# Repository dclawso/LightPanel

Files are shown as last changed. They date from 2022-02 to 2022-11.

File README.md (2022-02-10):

# LED light panel
So, I put my new Creality Ender 3 v2 in an enclosure. Now my PiCam can't see anything, so I needed some light. Since I love to tinker, I decided to build a LED light source for inside the enclosure.

I found a 8x32 LED panel [ACEIRMC 2pcs WS2812 5050SMD Individual Addressable 8X32 256 Pixels LED Matrix](https://www.amazon.com/dp/B08XZHRV3S?th=1), under $20 each. 

## The 3d printed stuff

Since the panel was flexible, I needed a frame to hold it. This led to the beginning of a 3d print project. The SCAD files are in the models folder.
The parts consit of two halves for the light panel and a control box for the power supply and the microcontroller.

NOTE: There currently is no cover for the control box.

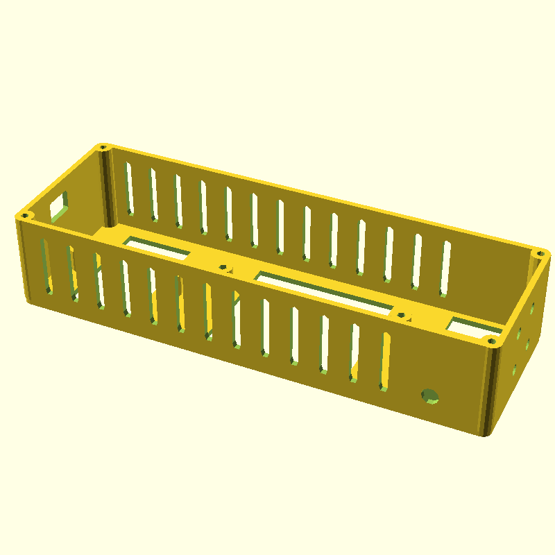
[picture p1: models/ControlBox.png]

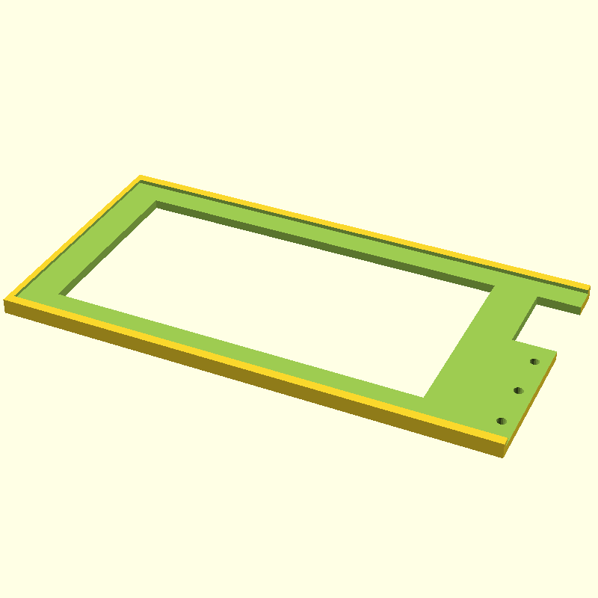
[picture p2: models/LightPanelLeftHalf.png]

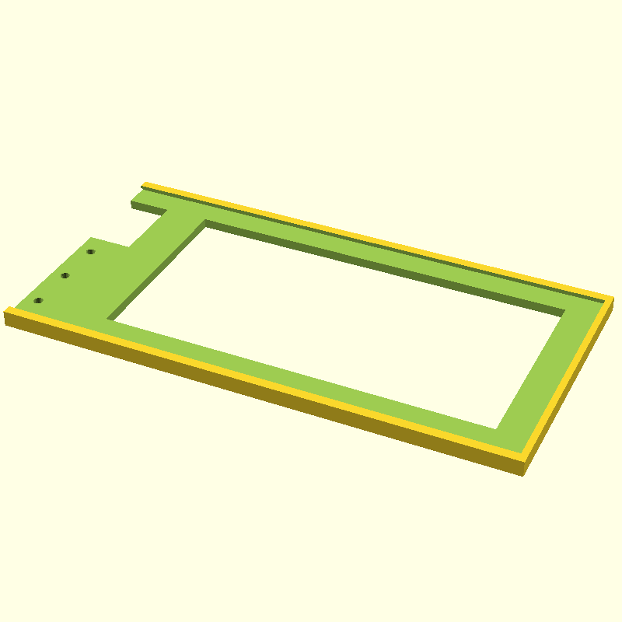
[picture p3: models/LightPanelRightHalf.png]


## The electronics

The brains of the light panel is an Arduino Nano v3. The power supply is a [Teyleten Robot 100W 6A DC-DC Buck Converter 10-90V](https://www.amazon.com/dp/B09FNBSZTR) which is way more power than required, but it has the capability to handle the 48V output available from the Ender 3's power supply and can handle enough current for the LED panel.

Connnection to the Raspberry Pi running [Octoprint](https://octoprint.org/) was originally going to be serial over USB, but there were two problems, another cable, and 5v from the Pi colliding with 5v from the high power powersupply. To solve this issue, add an HC06 bluetooth dongle.

## The software

The original idea was just to have th Arduino set all of the LEDs to max white and let it go. Where is the fun in that? After playing with several of the [FastLED](https://fastled.io/) examples, more colors and different settings were needed.

A simple command set was needed to allow for changing the color and intensity of the LEDs. This simple command set only supports setting the entire panel to one color, although it is possible for the Nano to set color for each LED individually.

The communication with the bluetooth dongle is via [AltSoftSerial](https://www.arduino.cc/reference/en/libraries/altsoftserial/). Since FastLED can hold the atmel processor for about 1.6ms to update the panel and AltSoftSerial is only able to delay an interrupt by about 1 bit time, the command set would have to be very simple.

There are currently two commands:

| Command|Usage | Description |
| -- | -- | -- |
| i | iddd | Set the intensity, replace ddd with a value between 0-100 to set intensity percentage. |
| c | cRRGGBB | Set the color of the panel, RRGGBB is the hex value for the RGB color. |
| p | pdddRRGGBBrrggbb | Set the LED panel as an progress meter. ddd is the percentage complete. RRGGBB is the hex value for the foreground color, rrggbb is the hex value for the background color. The percentage of the panel closest to the the provided progress percentage will consist of the foreground color.

The commands are received via the RFCOMM interface. Each character is echoed back and the result, 0, 1, or -1 is returned. -1 indicates the command was not understood. 1 indicates the command failed, and 0 indicates the command was successful. The LED panel is updated on one second intervals, so the command may take up to a second to take effect.

## Pictures

These are pictures of the prototype control box. This was the original control box with the print stopped at about 8mm in height. This allowed a test assembly, which resulted in modifications. The control box SCAD file contains a control box which has been modified as a result of this test fitting.

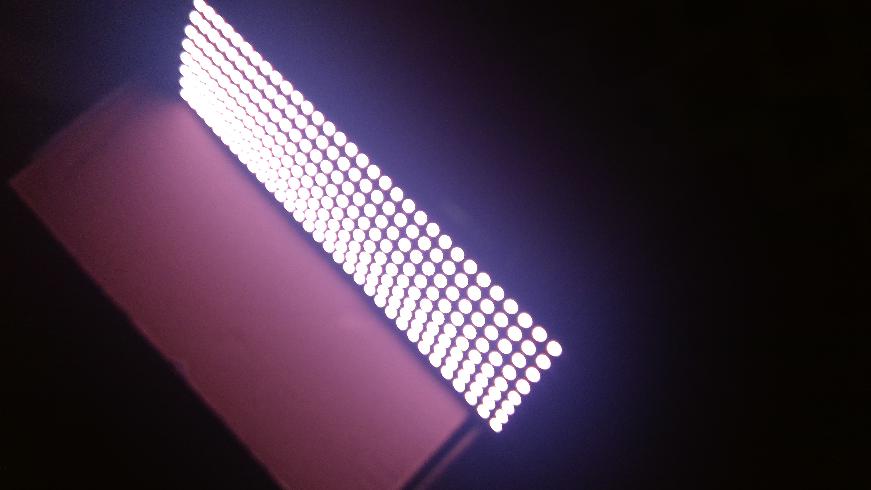
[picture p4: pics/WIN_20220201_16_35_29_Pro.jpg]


Panel after initial power-on.

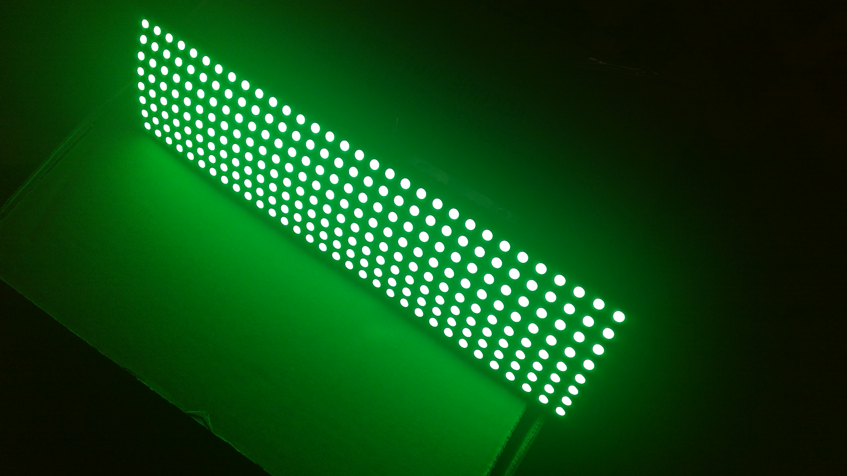
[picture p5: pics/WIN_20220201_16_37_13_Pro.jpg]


Panel after receiving 'c00ff00' command.

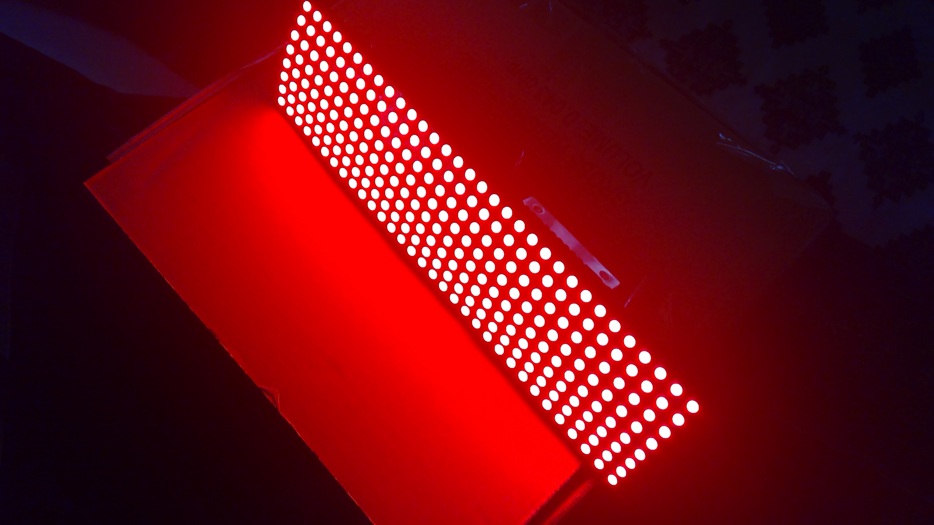
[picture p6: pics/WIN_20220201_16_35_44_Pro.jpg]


Panel after receiving 'cff0000' command.

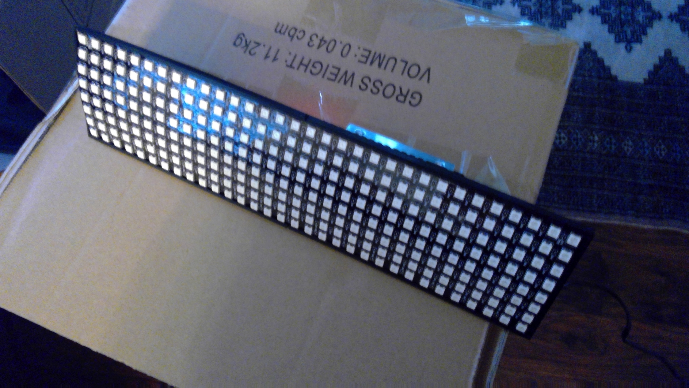
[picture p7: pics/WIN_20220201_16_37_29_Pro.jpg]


Panel when unpowered.

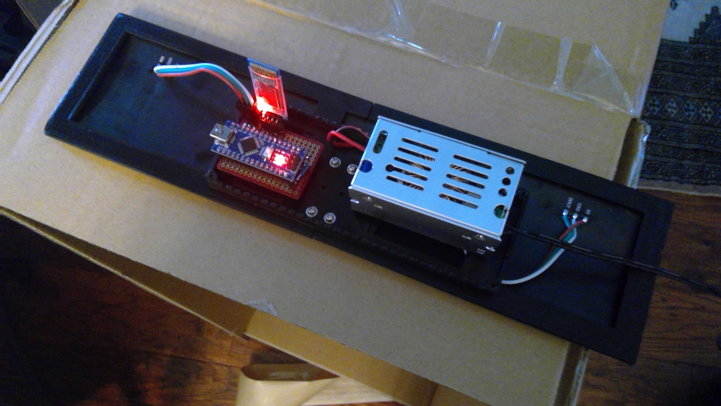
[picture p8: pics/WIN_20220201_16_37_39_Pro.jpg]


Back view of panel.

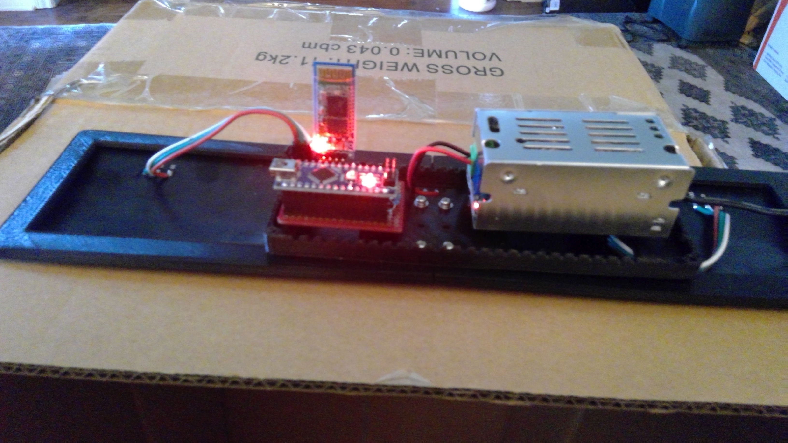
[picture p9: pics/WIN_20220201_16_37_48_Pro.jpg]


Side view of panel.

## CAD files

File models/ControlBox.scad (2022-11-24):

// MIT License
//
// Copyright (c) 2022 David Lawson
//
// Permission is hereby granted, free of charge, to any person obtaining a copy
// of this software and associated documentation files (the "Software"), to deal
// in the Software without restriction, including without limitation the rights
// to use, copy, modify, merge, publish, distribute, sublicense, and/or sell
// copies of the Software, and to permit persons to whom the Software is
// furnished to do so, subject to the following conditions:
//
// The above copyright notice and this permission notice shall be included in all
// copies or substantial portions of the Software.
//
// THE SOFTWARE IS PROVIDED "AS IS", WITHOUT WARRANTY OF ANY KIND, EXPRESS OR
// IMPLIED, INCLUDING BUT NOT LIMITED TO THE WARRANTIES OF MERCHANTABILITY,
// FITNESS FOR A PARTICULAR PURPOSE AND NONINFRINGEMENT. IN NO EVENT SHALL THE
// AUTHORS OR COPYRIGHT HOLDERS BE LIABLE FOR ANY CLAIM, DAMAGES OR OTHER
// LIABILITY, WHETHER IN AN ACTION OF CONTRACT, TORT OR OTHERWISE, ARISING FROM,
// OUT OF OR IN CONNECTION WITH THE SOFTWARE OR THE USE OR OTHER DEALINGS IN THE
// SOFTWARE.

use <controlboxparts.scad>

union() {
    difference() {
        control_box(160,50, 32);
        mounting_holes(160,5,20);
        // make a cutouts to save filament and print time
        translate([65,5,-2]) translate([25,21,5]) cube([50,42,10],center=true);
        translate([12.5,5,-2]) translate([12.5,21,5]) cube([25,42,10],center=true);

        // add hole for power connector
        translate([145,0,10]) rotate([90,0,0]) cylinder(r=2.9,h=10);
        // add hole for mini usb connector
        translate([-2,22.5,25]) rotate([90,0,90]) mini_usb_cutout();
        
        // screw holes on end for future mounting possibilies
        translate([160,27.5,17.5]) rotate([90,0,90]) union() {
            $fn=16;
            translate([-7,-7,0]) cylinder(r=2,h=10,center=true);
            translate([-7,7,0]) cylinder(r=2,h=10,center=true);
            translate([7,-7,0]) cylinder(r=2,h=10,center=true);
            translate([7,7,0]) cylinder(r=2,h=10,center=true);
        }
        
        // side vents
        for ( y = [-4, 50] ) {
            for ( i = [ 10 : 10 : 130]) {
                translate([i,y,8]) rotate([-90,-90,0]) slot([0,0,0],[20,0,0], 3, 10);
            }
        }
    }


    // add screw posts for nano mount
    translate([25,22.5,2]) {
        union() {
            screw_post(2.5, 8, [-18.5,0,0]);
            screw_post(2.5, 8, [18.5,0,0]);
        }
    }
    
    // add screw posts for power supply mount
    translate([90,33,2]) {
        union() {
            screw_post(3, 8, [-32.5,0,0]);
            screw_post(3, 8, [32.5,0,0]);
        }
    }
}

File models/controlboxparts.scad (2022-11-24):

// MIT License
//
// Copyright (c) 2022 David Lawson
//
// Permission is hereby granted, free of charge, to any person obtaining a copy
// of this software and associated documentation files (the "Software"), to deal
// in the Software without restriction, including without limitation the rights
// to use, copy, modify, merge, publish, distribute, sublicense, and/or sell
// copies of the Software, and to permit persons to whom the Software is
// furnished to do so, subject to the following conditions:
//
// The above copyright notice and this permission notice shall be included in all
// copies or substantial portions of the Software.
//
// THE SOFTWARE IS PROVIDED "AS IS", WITHOUT WARRANTY OF ANY KIND, EXPRESS OR
// IMPLIED, INCLUDING BUT NOT LIMITED TO THE WARRANTIES OF MERCHANTABILITY,
// FITNESS FOR A PARTICULAR PURPOSE AND NONINFRINGEMENT. IN NO EVENT SHALL THE
// AUTHORS OR COPYRIGHT HOLDERS BE LIABLE FOR ANY CLAIM, DAMAGES OR OTHER
// LIABILITY, WHETHER IN AN ACTION OF CONTRACT, TORT OR OTHERWISE, ARISING FROM,
// OUT OF OR IN CONNECTION WITH THE SOFTWARE OR THE USE OR OTHER DEALINGS IN THE
// SOFTWARE.

// make a cutout for the mini USB connector
//     this module makes the positive element to use in a difference to cut it out.
module mini_usb_cutout() {
    hull() {
        translate([-4.5,-3,0]) cylinder(r=1,h=10,center=true);
        translate([-4.5,3,0]) cylinder(r=1,h=10,center=true);
        translate([4.5,-3,0]) cylinder(r=1,h=10,center=true);
        translate([4.5,3,0]) cylinder(r=1,h=10,center=true);
    }
}

// make a screw post for the screw diameter indicated. The height is the height of the hole
// in the center.
module screw_post(diameter, height,location=[0,0,0])
{
    $fn=64;
    r = diameter/2;
    translate(location)
    translate([0,0,height/2])
    difference() {
        cylinder(height,r+2.0,r+2.0,center = true);
        translate([0,0,1])
            cylinder(height-1, r, r, center = true);
        
    }
}

// make a cube with a corner at the origin. easier for placing exactly
module ocube(length, width, height) {
    translate([length/2, width/2, height/2])
        cube([length, width, height], center=true);
}

// make a positive which can be used to cut a slot with rounded ends
module slot(loc1, loc2, dia, height) {
    $fn=64;
    hull() {
        translate(loc1) cylinder(r=dia/2, h=height);
        translate(loc2) cylinder(r=dia/2, h=height);
    }
}

// make the very specific control box.
//    rather than being subtractive, the main box is built as a union of floor, walls, and screw posts.
module control_box(length, width, height) {
    $fn=64;
    translate([0,0,0]) {
        union() {
            // base
            translate([1,1,0]) 
                    minkowski() {
                        translate([length/2+.3, width/2+.3, .5])
                        cube([length, width, 1], center=true);
                        cylinder(r=3, h=1);
                    }

            // walls
            translate([1,-1.85,2]) 
                    ocube(length+1,2,height);
            translate([1,width+2.45,2]) 
                    ocube(length+1,2,height);
            translate([-1.85,1,2]) 
                    ocube(2,width+1,height);
            translate([length+2.45,1,2]) 
                    ocube(2,width+1,height);

            // corner screw posts
            $fn=16;
            screw_post(2.5, height, [1.25, 1.25, 2]);
            screw_post(2.5, height, [1.25, width+1.25, 2]);
            screw_post(2.5, height, [length+1.25, 1.25, 2]);
            screw_post(2.5, height, [length+1.25, width+1.25, 2]);
        }
    }
}

module mounting_holes(length,hole_side_offset=10, hole_end_offset=20) {
    $fn=16;
    // make holes to match the screw pattern of the ligth panel halves
    translate([length-hole_end_offset,hole_side_offset,-2]) translate([0,0,0]) cylinder(r=1.5,h=10);
    translate([length-hole_end_offset,hole_side_offset,-2]) translate([0,15,0]) cylinder(r=1.5,h=10);
    translate([length-hole_end_offset,hole_side_offset,-2]) translate([0,30,0]) cylinder(r=1.5,h=10);
    translate([length-hole_end_offset,hole_side_offset,-2]) translate([10,0,0]) cylinder(r=1.5,h=10);
    translate([length-hole_end_offset,hole_side_offset,-2]) translate([10,15,0]) cylinder(r=1.5,h=10);
    translate([length-hole_end_offset,hole_side_offset,-2]) translate([10,30,0]) cylinder(r=1.5,h=10);

    // add pass through for power cables from LED panel
    translate([length-hole_end_offset-15,35,-2]) translate([10,7,0]) cube([20,8,10]);
}

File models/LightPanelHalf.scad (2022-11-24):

// MIT License
//
// Copyright (c) 2022 David Lawson
//
// Permission is hereby granted, free of charge, to any person obtaining a copy
// of this software and associated documentation files (the "Software"), to deal
// in the Software without restriction, including without limitation the rights
// to use, copy, modify, merge, publish, distribute, sublicense, and/or sell
// copies of the Software, and to permit persons to whom the Software is
// furnished to do so, subject to the following conditions:
//
// The above copyright notice and this permission notice shall be included in all
// copies or substantial portions of the Software.
//
// THE SOFTWARE IS PROVIDED "AS IS", WITHOUT WARRANTY OF ANY KIND, EXPRESS OR
// IMPLIED, INCLUDING BUT NOT LIMITED TO THE WARRANTIES OF MERCHANTABILITY,
// FITNESS FOR A PARTICULAR PURPOSE AND NONINFRINGEMENT. IN NO EVENT SHALL THE
// AUTHORS OR COPYRIGHT HOLDERS BE LIABLE FOR ANY CLAIM, DAMAGES OR OTHER
// LIABILITY, WHETHER IN AN ACTION OF CONTRACT, TORT OR OTHERWISE, ARISING FROM,
// OUT OF OR IN CONNECTION WITH THE SOFTWARE OR THE USE OR OTHER DEALINGS IN THE
// SOFTWARE.

module slot(w,l,h) {
    hull() {
        cylinder(d=w,h=h);
        translate([l,0,0]) cylinder(d=w,h=h);
    }
}

module LightPanelHalf(length=160,width=80,ridge=2) {
    difference() {
        // main box for the panel
        cube([length+1,width+2,5]);
        
        /// cut out the top of the panel
        translate([ridge+1,ridge+1,3.9]) cube([length+ridge,width-ridge*2,2]);
        
        // make a notch for the LED panel
        translate([1,1,3]) cube([length+1,width,1]);
        
        // space for DIN,DOUT cables.
        translate([30,50,-1]) cube([20,20,8]);

        // make cutout for power wires in the center
        translate([length-15+ridge,50,-1]) cube([15+1,25,5]);
        
        $fn=64;
        translate([156, 10, 0]) {
            translate([1.5,1.5,-1]) cylinder(r=1.5,h=10);

            translate([0,15,0])
            translate([1.5,1.5,-1]) cylinder(r=1.5,h=10);

            translate([0,30,0])
            translate([1.5,1.5,-1]) cylinder(r=1.5,h=10);      
        }
        translate([20,15,-1]) rotate([0,0,135]) slot(5,12,10);
        translate([30,15,-1]) rotate([0,0,135]) slot(5,27,10);
        for (x=[40,50,60,70,80,90]) {
            translate([x,15,-1]) rotate([0,0,135]) slot(5,40,10);
        }
        translate([100,15,-1]) rotate([0,0,135]) slot(5,60,10);
        translate([110,15,-1]) rotate([0,0,135]) slot(5,75,10);
        for (x=[120,130,140]) {
            translate([x,15,-1]) rotate([0,0,135]) slot(5,80,10);
        }
        translate([140,25,-1]) rotate([0,0,135]) slot(5,67,10);
        translate([140,35,-1]) rotate([0,0,135]) slot(5,52,10);
        translate([140,45,-1]) rotate([0,0,135]) slot(5,37,10);
        translate([140,55,-1]) rotate([0,0,135]) slot(5,23,10);
        translate([140,65,-1]) rotate([0,0,135]) slot(5,8,10);
    }
}

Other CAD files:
models/ControlBoxLid.scad
models/LightPanelLeftHalf.scad
models/LightPanelRightHalf.scad
models/LightPanelRighttHalf.scad

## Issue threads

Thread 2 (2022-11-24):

Flip buck converter mounting holes

dclawso, 2022-11-24:
The mounting holes for the buck converter in the control box need to be flipped to turn the buck converter around. This makes wiring better.

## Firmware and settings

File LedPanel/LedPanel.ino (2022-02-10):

// MIT License
//
// Copyright (c) 2022 David Lawson
//
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
#include <AltSoftSerial.h>

#include <FastLED.h>

#define CMDBUF_SIZE 32
#define CMDBUF_INDEX_MASK (CMDBUF_SIZE - 1)

#define LED_FRAME_RATE  (1000/25)

#define DATA_PIN    3
//#define CLK_PIN   4
#define LED_TYPE    WS2811
#define COLOR_ORDER GRB
#define NUM_LEDS    256
CRGB leds[NUM_LEDS];
bool ledsUpdated = false;

CRGB foreground = CRGB(0xffffff);

// Params for width and height
const uint8_t kMatrixWidth = 8;
const uint8_t kMatrixHeight = 32;

// Param for different pixel layouts
const bool    kMatrixSerpentineLayout = true;
const bool    kMatrixVertical = false;

#define BRIGHTNESS          90
#define FRAMES_PER_SECOND  120

AltSoftSerial bt;

uint16_t XY( uint8_t x, uint8_t y)
{
  uint16_t i;
  
  if( kMatrixSerpentineLayout == false) {
    if (kMatrixVertical == false) {
      i = (y * kMatrixWidth) + x;
    } else {
      i = kMatrixHeight * (kMatrixWidth - (x+1))+y;
    }
  }

  if( kMatrixSerpentineLayout == true) {
    if (kMatrixVertical == false) {
      if( y & 0x01) {
        // Odd rows run backwards
        uint8_t reverseX = (kMatrixWidth - 1) - x;
        i = (y * kMatrixWidth) + reverseX;
      } else {
        // Even rows run forwards
        i = (y * kMatrixWidth) + x;
      }
    } else { // vertical positioning
      if ( x & 0x01) {
        i = kMatrixHeight * (kMatrixWidth - (x+1))+y;
      } else {
        i = kMatrixHeight * (kMatrixWidth - x) - (y+1);
      }
    }
  }
  
  return i;
}


void setup() {
   Serial.begin(9600);
   bt.begin(9600);
   delay(3000);
   FastLED.addLeds<LED_TYPE,DATA_PIN,COLOR_ORDER>(leds, NUM_LEDS).setCorrection(TypicalLEDStrip);
  //FastLED.addLeds<LED_TYPE,DATA_PIN,CLK_PIN,COLOR_ORDER>(leds, NUM_LEDS).setCorrection(TypicalLEDStrip);

  // set master brightness control
  FastLED.setBrightness(BRIGHTNESS);

  uint16_t pos;
  for (pos=0;pos<NUM_LEDS;pos++) {
    leds[pos] = CRGB::White;
  }
}

uint8_t y = 0;

void showLed(unsigned long cur) {
  static unsigned long last = 0;
  if ((cur - last) > LED_FRAME_RATE) {
    last = cur;
    if (!ledsUpdated) {
      FastLED.show();
      ledsUpdated = true; 
    }
  }
}

char cmdbuf[CMDBUF_SIZE];
char safe = 0;
int cmdbufindex=0;

unsigned char hexchartoval(char c) {
  c = toupper(c);
  c -= '0';
  if (c > 9) {
    c -= 'A' - '9' - 1;
  }
  return c;
}
unsigned char getFromAscii(char *p) {
  return (hexchartoval(p[0]) << 4) | hexchartoval(p[1]);
}

void getColor(CRGB& rgb, char *p) {
  rgb.r = getFromAscii(&p[0]);
  rgb.g = getFromAscii(&p[2]);
  rgb.b = getFromAscii(&p[4]);
}

int setIntensity() {
  int i = atoi(&cmdbuf[1]);

  if (i > 100) {
    return 1;
  }
  FastLED.setBrightness(i);
  return 0;
}

int setColor() {
  if ((cmdbufindex & CMDBUF_INDEX_MASK) != 7) {
    return 1;  
  }

  getColor(foreground, &cmdbuf[1]);

  int i;

  for (i=0; i<NUM_LEDS; i++) {
    leds[i] = foreground;
  }

  return 0;
}

void drawRow(int x, CRGB& color) {
  for (int i=0; i<kMatrixWidth; i++) {
    leds[XY(i,x)] = color;
  }
}

int setMeter() {
  int numChars = cmdbufindex & CMDBUF_INDEX_MASK;
  if (numChars != 4 && numChars != 10 && numChars != 16) {
    return 1;
  }

  char tempchar = cmdbuf[4];
  cmdbuf[4] = 0;
  int percentage = atoi(&cmdbuf[1]);
  if (percentage < 0 || percentage > 100) {
    return 1;
  }
  cmdbuf[4] = tempchar;

  CRGB bg;
  bg.r = 0xff - foreground.r;
  bg.g = 0xff - foreground.g;
  bg.b = 0xff - foreground.b;
  CRGB fg = foreground;

  if (numChars >= 10) {
    getColor(fg, &cmdbuf[4]);
  }

  if (numChars >= 16) {
    getColor(bg, &cmdbuf[10]);
  }

  int fgRows = kMatrixHeight * percentage / 100;

  for (int i=0; i<kMatrixHeight; i++) {
    drawRow(i, (i > fgRows) ? bg : fg);
  }

  return 0;
}

int test() {
  int numChars = cmdbufindex & CMDBUF_INDEX_MASK;
  if (numChars != 4 && numChars != 10) {
    return 1;
  }

  CRGB c = CRGB(0xff0000);
  if (numChars == 10)  getColor(c, &cmdbuf[4]);
  cmdbuf[4] = 0;
  int xy = atoi(&cmdbuf[1]);
  int x = xy/100;
  int y = xy % 100;

  leds[XY(x,y)] = c;
  return 0;
}

void processcmd() {
  cmdbuf[cmdbufindex] = 0;
  int rc = -1;
  switch (cmdbuf[0]) {
    case 'i':
    case 'I':
      rc = setIntensity();
      break;
    case 'c':
    case 'C':
      rc = setColor();
      break;
    case 'P':
    case 'p':
      rc = setMeter();
      break;
    case 'T':
    case 't':
      rc = test();
      break;
  }
  cmdbufindex = 0;
  if (rc == 0) {
    ledsUpdated = false;
  }
  bt.println(rc);
}

void handleSerial() {
  char c;

  if (bt.available()) {
    c = bt.read();
    bt.print(c);
    if (c == 0x08) {
      if ((cmdbufindex & CMDBUF_INDEX_MASK) > 0) {
        cmdbufindex--;
        bt.print('\b');
        bt.print(' ');
        bt.print('\b');
      }
    } else if (c == 0x0d) {
      bt.print('\n');
      processcmd();
    } else {
      cmdbuf[cmdbufindex++ & CMDBUF_INDEX_MASK] = c;
    }
  }
}
void loop() {
  unsigned long cur = millis();
  showLed(cur);

  handleSerial();
}

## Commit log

2022-02-01 Prototype build
    [CE3_ControlBox.3mf, CE3_LightPanelRighttHalf.3mf, CE3_lightpanelhalf.3mf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]
2022-02-01 removed slicer projects, moved models to folder
    [CE3_ControlBox.3mf, CE3_LightPanelRighttHalf.3mf, CE3_lightpanelhalf.3mf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]
2022-02-01 added arduino code
2022-02-02 Added copyright info, readme
    [ControlBox.scad, LightPanelHalf.scad, LightPanelLeftHalf.scad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]
2022-02-02 fixed return value for setColor
    [LedPanel.ino]
2022-02-02 added vsccode files for arduino project
2022-02-02 added makefile for building images of scad files, cleaned up scad files
    [ControlBox.scad, LightPanelHalf.scad, LightPanelLeftHalf.scad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]
2022-02-10 debugged and fixed progress meter
    [LedPanel.ino]
2022-02-10 Fix end holes for future mounting options on control box
    [ControlBox.scad]
2022-11-24 better fit for LED panel
    [ControlBox.scad, LightPanelHalf.scad, LightPanelLeftHalf.scad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]
2022-11-24 add control box lid model
    [ControlBox.scad, ControlBoxLid.scad, controlboxparts.scad]
